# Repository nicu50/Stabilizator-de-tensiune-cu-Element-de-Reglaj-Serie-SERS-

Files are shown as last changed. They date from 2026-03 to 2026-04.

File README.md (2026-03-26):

# Stabilizator de tensiune cu Element de Reglaj Serie (SERS)

## Descriere
Acest proiect prezintă proiectarea, simularea și analiza unui stabilizator liniar cu element de reglaj serie.  
Proiectul a fost realizat în cadrul **Universitatea Politehnica din București, Facultatea de Electronică, Telecomunicații și Tehnologia Informației**.

## Principiu de funcționare
Stabilizatorul menține constantă tensiunea pe sarcină printr-un proces de reglare automată:
- O fracțiune din tensiunea de ieșire este comparată cu o tensiune de referință stabilă (diodă Zener + sursă de curent constant).
- Semnalul de eroare este amplificat și comandă elementul regulator serie (tranzistoare în conexiune Darlington).
- Include protecție la supracurent pentru a limita curentul maxim la 0,4 A.

## Cerințe de proiectare 
Să se proiecteze si realizeze un stabilizator de tensiune cu ERS având următoarele caracteristici: 
- Tensiunea de ieșire reglabilă în intervalul: N/3 – N/2 = 3.66 – 5.5[V];
- Element de reglaj serie;
- Sarcina la ieșire 50N = 550 [ohm];
- Deriva termică < 2 mV/C;
- Protecție la suprasarcină prin limitarea curentului tranzistorului element de reglaj serie la maxim 0,4 A;
- Tensiune de intrare în intervalul 2/3N - 3/4N = 7.33 – 8.25[V];
- Domeniul temperaturilor de funcționare: 0-70 C (verificabil prin testare în temperatură);
- Amplificarea în tensiune minimă (în buclă deschisă) a amplificatorului de eroare: 200; 

## Schema bloc
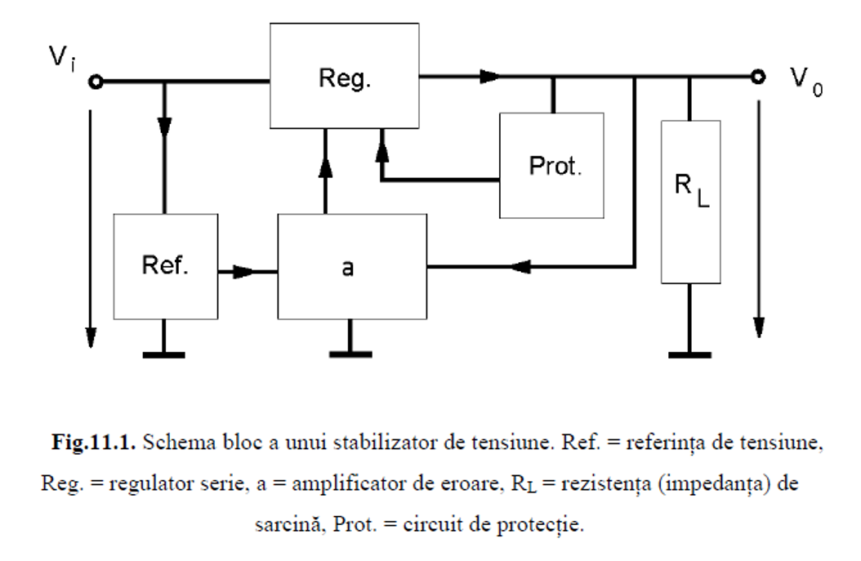
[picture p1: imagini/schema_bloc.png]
Schema bloc


## Schema electrică 
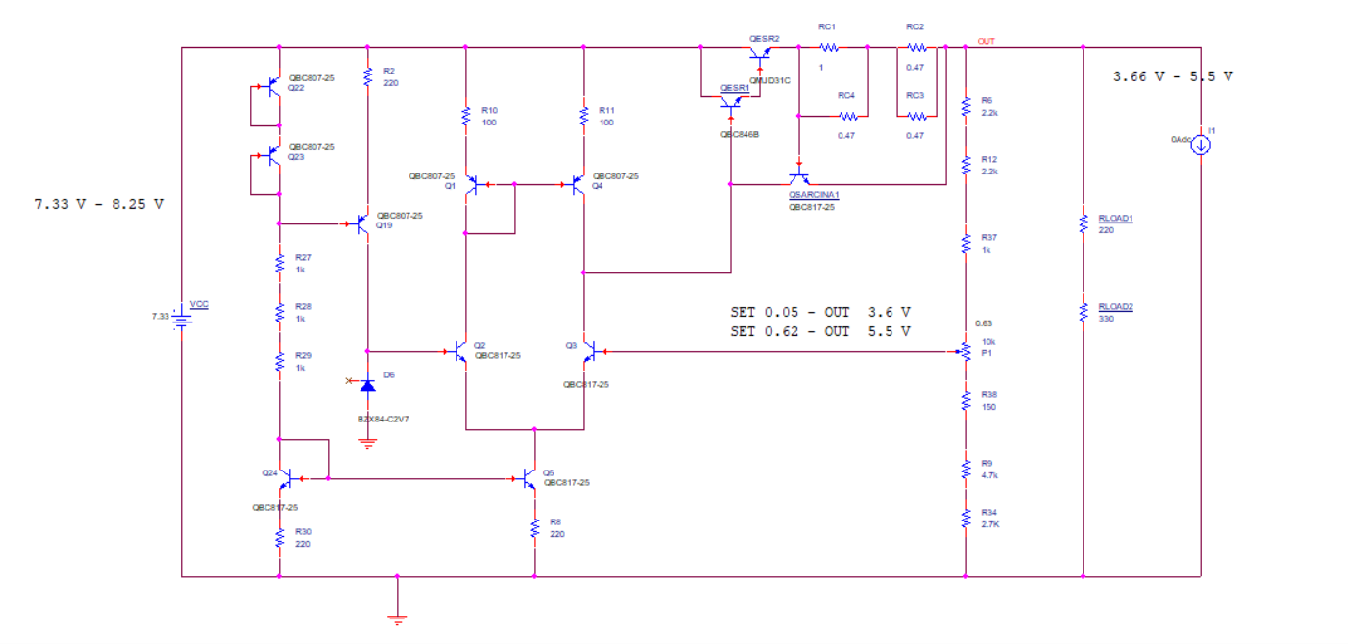
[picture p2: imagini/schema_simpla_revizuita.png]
Schema electrica


## Punctul static de funcționare
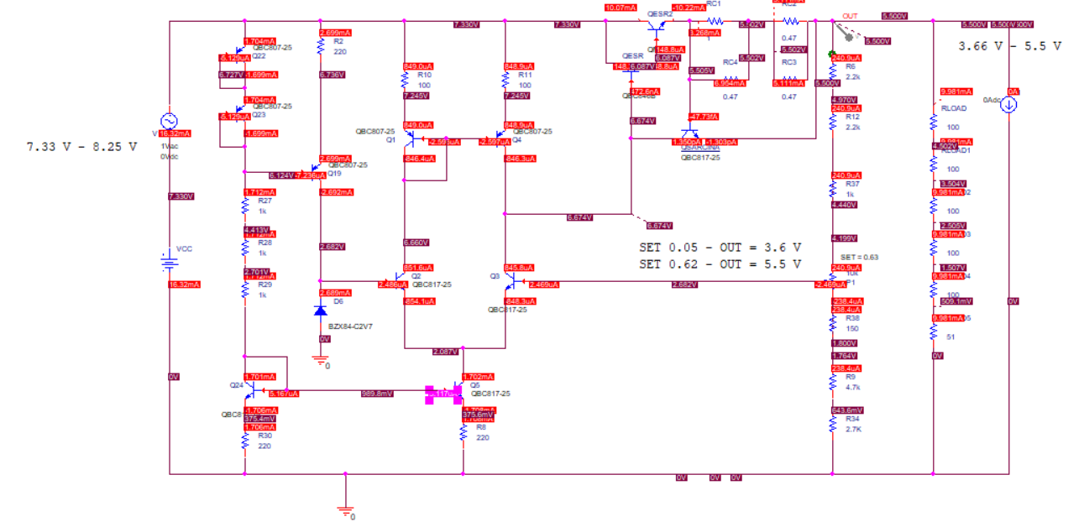
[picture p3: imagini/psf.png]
Simulare


---

## Proiectare Hardware (PCB)

Proiectul a fost realizat în tehnologie **SMT (Surface Mount Technology)** pe un cablaj dublu strat, respectând constrângerile de spațiu și specificațiile din tema de proiectare.

### Caracteristici Tehnice Cablaj:
* **Dimensiuni placă:** 40mm x 40mm
* **Material:** FR4 (dublu strat)
* **Grosime placă:** 1.5 mm
* **Grosime folie cupru:** 18 $\mu m$

### Layout PCB (Previzualizare)
Mai jos este prezentată captura de ecran cu layout-ul PCB-ului realizat în **OrCAD Allegro PCB Editor**.

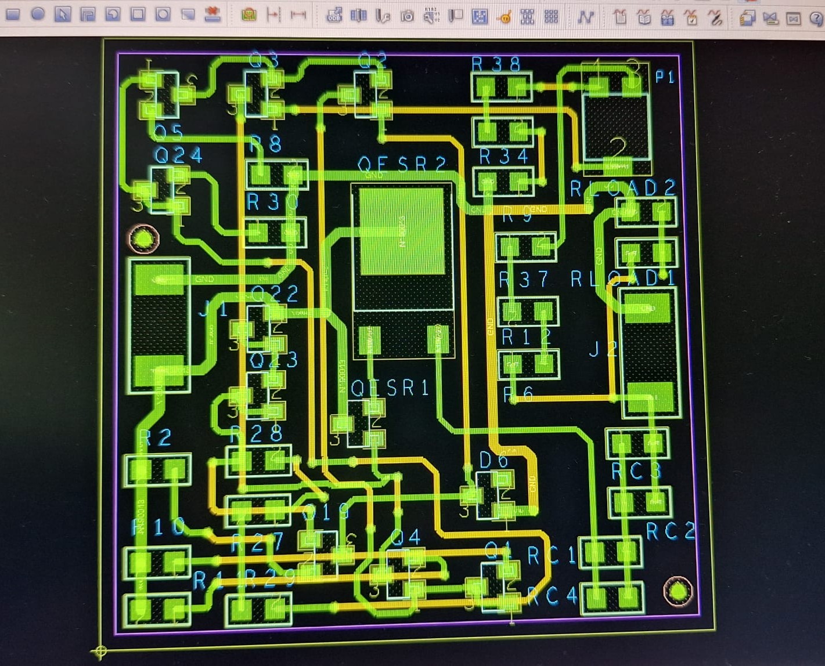
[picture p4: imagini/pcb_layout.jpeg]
Layout PCB


> **Notă:** Traseele de pe stratul TOP sunt evidențiate cu verde, iar cele de pe stratul BOTTOM cu galben.

---

## Autor
Tănăselea Neculai

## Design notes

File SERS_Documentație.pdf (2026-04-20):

## UNIVERSITATEA POLITEHNICA dinBUCUREȘTI

## Facultatea de Electronică, Telecomunicaţii şi Tehnologia Informaţiei Departamentul de Dispozitive, Circuite și Arhitecturi Electronice

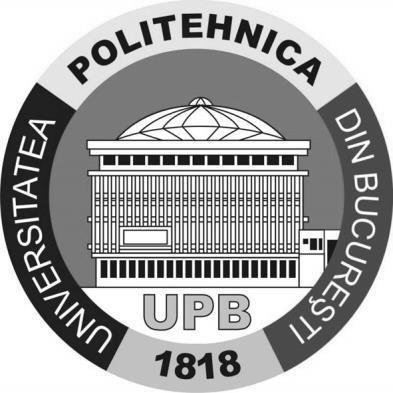
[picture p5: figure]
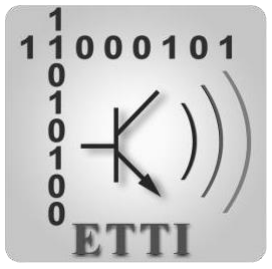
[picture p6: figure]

# PROIECT 1 Stabilizator de tensiune

## Profesori coordonatrori: Ş.l.Dr.Ing. Cristea Miron Dr.Ing. Drăghici Niculina

## Student: Tănăselea Neculai Grupa 433C Anul III

## Anul universitar 2025-2026

## CUPRINS

1. Date inițiale de proiectare | 3
1.1 Enunțul temei de proiectare | 3
1.2 Schema bloc a montajului electric | 3
1.3 Schema electrică a montajului electric | 4
2. Conținut tehnic/științific al proiectului | 5
2.1 Descrierea funcționării schemei de proiectare | 5
2.2 Proiectarea schemei electrice în ORCAD | 7
2.3 BOM | 7
2.4 Punctulstatic de funcționare (curent, tensiune, putere) | 8
3. Simularea montajului electric | 10
4. Bibliografie și webografie | 13

## 1. Date inițiale de proiectare

### 1.1 Enunțul temei de proiectare ( N=11 )

Să se proiecteze sirealizeze un stabilizator de tensiune cu ERS având următoarele caracteristici:
- Tensiunea de ieșire reglabilă în intervalul: N/3 – N/2 = 3.66 – 5.5[V];
- Element de reglajserie;
- Sarcina la ieșire 50N = 550 [ohm];
- Deriva termică < 2 mV/C;
- Protecție la suprasarcină prin limitarea curentului tranzistorului element de reglaj serie la maxim 0,4 A;
- Tensiune de intrare în intervalul 2/3N - 3/4N = 7.33 – 8.25[V];
- Domeniul temperaturilor de funcționare: 0-70 C (verificabil prin testare în temperatură);
- Amplificarea în tensiune minimă (în buclă deschisă) a amplificatorului de eroare: 200;

### 1.2 Schema bloc a montajului electric

În schemă se observă următoarele componente:
- Ref – Referința de tensiune;
- a - Amplificator de eroare;
- Reg - Regulator serie;
- RL – Rezistenta de sarcină;
- Prot. - Circuit de
protectie;
La intrarea neinversoare a Amplificatorului de eroare se aplică
Referința de tensiune, oferită de blocul
Ref.

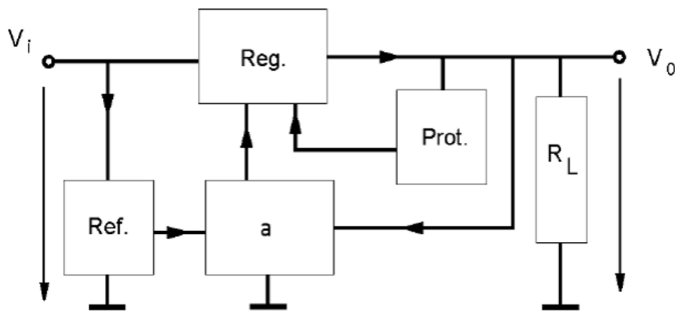
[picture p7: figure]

La intrarea inversoare a Amplificatorului de eroare se aplică, prin intermediul reacției negative, prin blocul RR, o fracțiune din tensiunea de ieșire. Regulatorul serie este comandat de Amplificatorul de eroare, care compară tensiunea dată de Referința de tensiune cu tensiunea preluată de la ieșire prin rețeaua de reacție RR. La acesta se adaugă un Circuit de protecție la suprasarcină.

### 1.3 Schema electrică a montajului electric

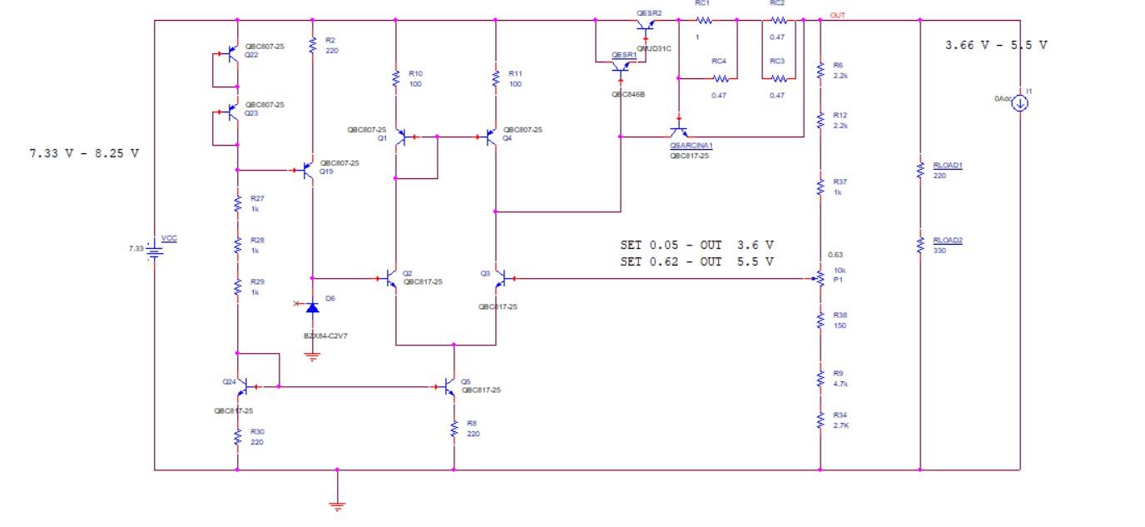
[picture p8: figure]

Circuitul este compus din următoarele blocuri:
- Q23,Q22,R27,R28,R29,Q30 genereaza curent
- Rețea reacție negativă R6, R12, R37, P1, R38, R9, R34
- Element reglaj serie: QESR1 si QESR2
- Protecția la suprasarcină: QSARCINA 1,RC1, RC2, RC3, RC4
- Q5 polarizeaza etajul diferential
- Q3 Q2 etaj diferential de tip NPN amplifica in curent si tensiune
- Q1 Q4 sarcina activa a etajului diferential egaleaza curentii pe cele doua ramuri

## 2. Conținut tehnic/științific al proiectului

### 2.1 Descrierea funcționării schemei de proiectare

Stabilizatoarele de tensiune sunt circuite electronice care mențin constantă tensiunea pe rezistența de sarcină (tensiunea stabilizată), în condițiile variației tensiunii de intrare (tensiunea nestabilizată), a curentului de sarcină și a temperaturii.
Schema prezentată este un stabilizator liniar serie cu reacție. Tensiunea de ieșire se menține constantă printr-un proces de reglare automată: o fracțiune din tensiunea de ieșire este comparată cu o tensiune de referință fixă. Semnalul de eroare rezultat este amplificat și comandă elementul regulator serie pentru a restabili valoarea prescrisă.
Stabilizatorul include protecție la supracurent, care limitează intensitatea curentului prin sarcină la o valoare presetată pentru a proteja tranzistorul regulator.

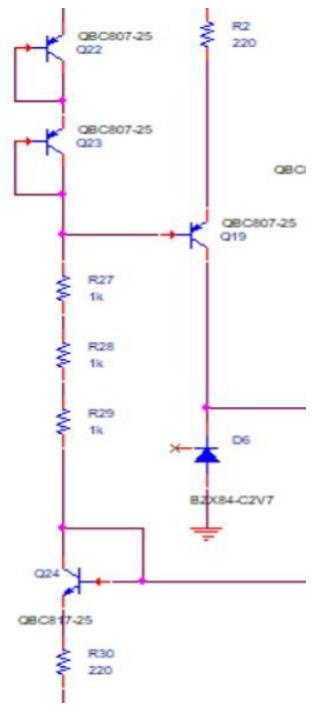
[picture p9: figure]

### 1. Referinta de tensiune

Referința de tensiune este asigurată de dioda Zener D6 (model BZX84-C2V7). Aceasta furnizează o tensiune stabilă de aproximativ 2.7 V la catodul său, care servește drept punct de comparație pentru amplificatorul de eroare.Pentru o stabilitate superioară, dioda Zener nu este alimentată printr-o simplă rezistență, ci printr-un generator de curent constant complex, format din tranzistoarele Q19, Q22, Q23, Q24 și rezistențele aferente.
Acest circuit asigură un curent constant prin dioda Zener (indiferent de fluctuațiile tensiunii de intrare VCC, garantând o tensiune de referință precisă ("zgomot" redus și impedanță dinamică mică).Componente cheie: D6 (Zener 2.7V), Q19, Q22, Q23, Q24 (Sursă de curent).

### 2. Amplificator de eroare

Amplificatorul de eroare este realizat sub forma unui amplificator diferențial cu tranzistoare bipolare. Etajul de intrare este format din perechea diferențială de tranzistoare PNP Q2 și Q3 (tip BC807-25). Baza lui Q2 primește tensiunea de referință (2.7V) de la dioda D6. Baza lui Q3 primește tensiunea de reacție (eșantionul din tensiunea de ieșire) de la potențiometrul P1.

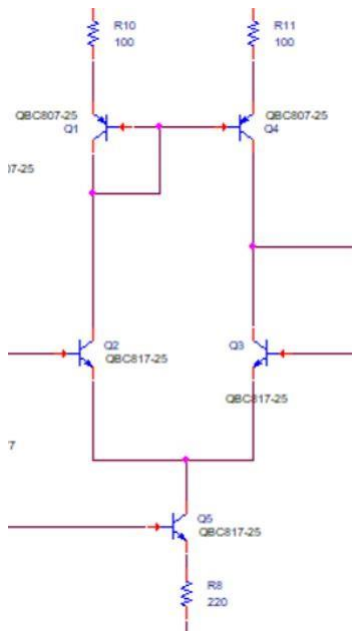
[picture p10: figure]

Sarcina acestui etaj diferențial este o oglindă de curent activă formată din tranzistoarele NPN Q2 și Q3 (tip BC817-25), care asigură o conversie eficientă a semnalului diferențial într-un semnal de comandă asimetric (single-ended) pentru etajul următor. Curentul de coadă al amplificatorului diferențial (tail current) este stabilit de tranzistorul Q5, care face parte din rețeaua de polarizare de la intrare

### 3. Element de reglaj serie

Elementulregulator serie este configurat ca o pereche Darlington, formată din tranzistorul pre-final QESR1 (BC846B) și tranzistorul de putere QESR2 (MJD31C).

În cel mai defavorabil caz (tensiune intrare maximă 8.25V și ieșire minimă 3.66V), căderea de tensiune pe tranzistor este de aproximativ 4.6V. La un curent de sarcină semnificativ, puterea disipată trebuie gestionată termic. Configurația Darlington asigură un factor de amplificare în curent (beta) foarte mare, permițând amplificatorului de eroare să comande sarcini mari cu un curent de bază foarte mic.

### 4. Rețeaua de reacție negativă

Aceasta este un divizor de tensiune rezistiv conectat la ieșirea stabilizatorului, care "citește" valoarea tensiunii de ieșire. Divizorul este compus din R37, Potențiometrul P1, R38, R9 și R34.
Tensiunea culeasă de pe cursorul potențiometrului P1 este aplicată bazei tranzistorului Q3 (intrarea inversoare a amplificatorului de eroare). Sistemul va ajusta ieșirea astfel încât tensiunea pe cursorul lui P1 să fie egală cu tensiunea de referință (2.7V).
Reglaj: Prin variația lui P1 (10k), se modifică raportul de divizare, permițând reglarea tensiunii de ieșire (OUT) în intervalul proiectat de aproximativ 3.6V – 5.5V.

### 5. Circuit de protecție

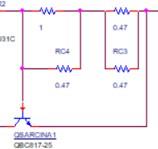
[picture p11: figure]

Schema este prevăzută cu un circuit de protecție la supracurent (limitare de curent), esențial pentru protejarea tranzistorului de putere QESR2 în cazul unui scurtcircuit sau al unei sarcini excesive.
Protecția este realizată cu tranzistorul QSARCINA1 (BC817-25) și grupul de rezistențe de sesizare a curentului conectate în serie cu ieșirea: RC1, RC4, RC3, RC2. Aceste rezistențe sunt conectate în paralel pentru a obține o valoare ohmică foarte mică și o capacitate de putere mai mare.

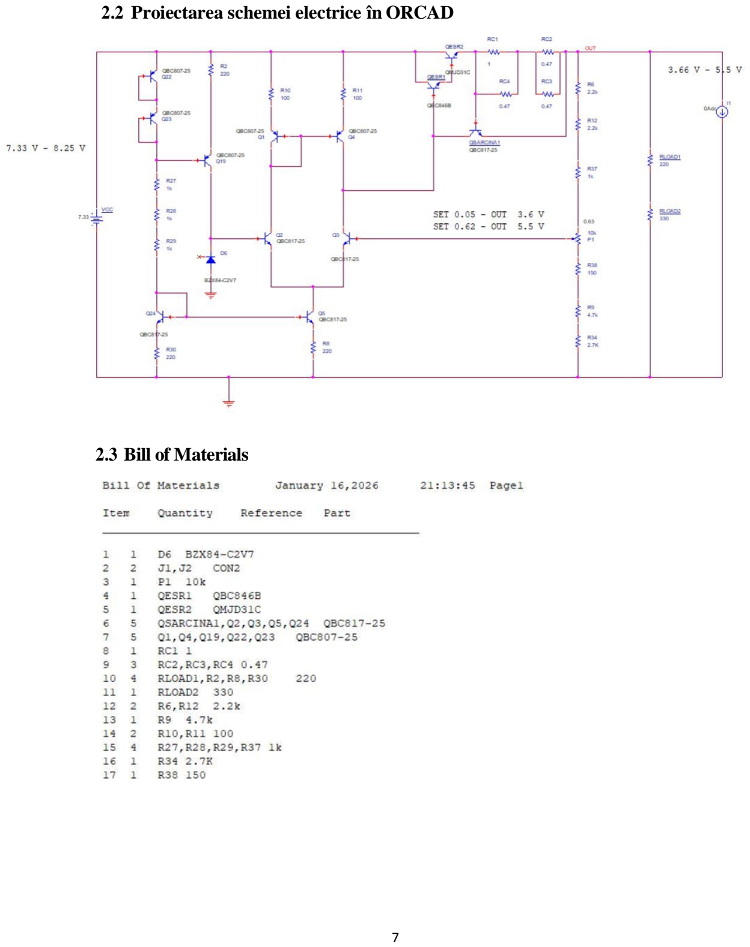
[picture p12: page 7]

### 2.2 Proiectarea schemei electrice în ORCAD

### 2.3 Bill of Materials

### 2.4 Punctulstatic de funcționare

1) CURENTI

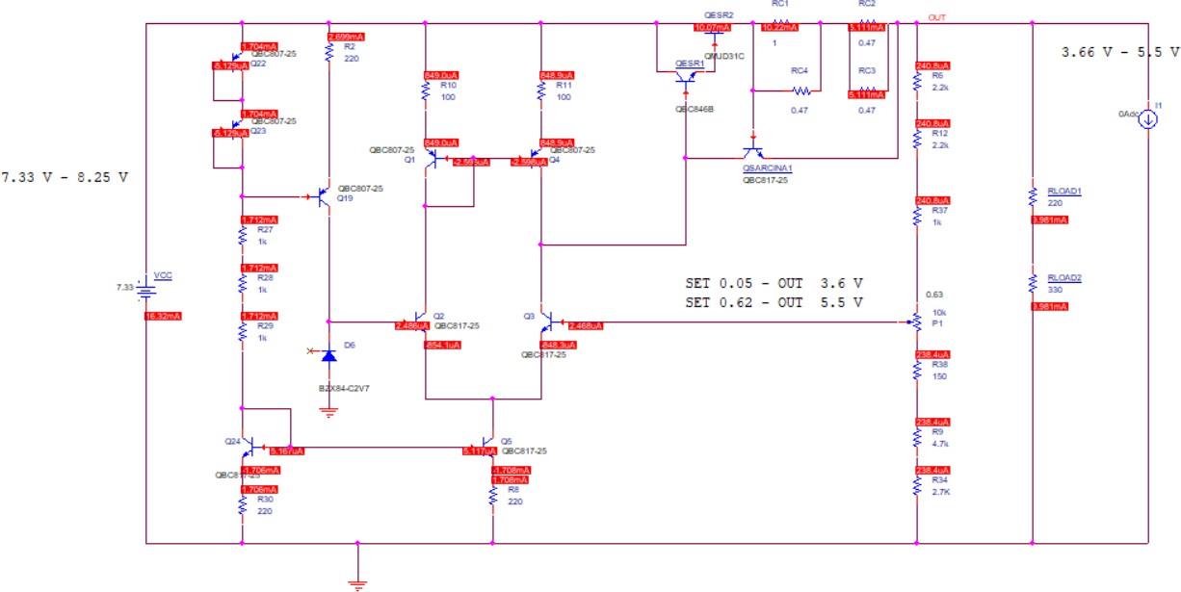
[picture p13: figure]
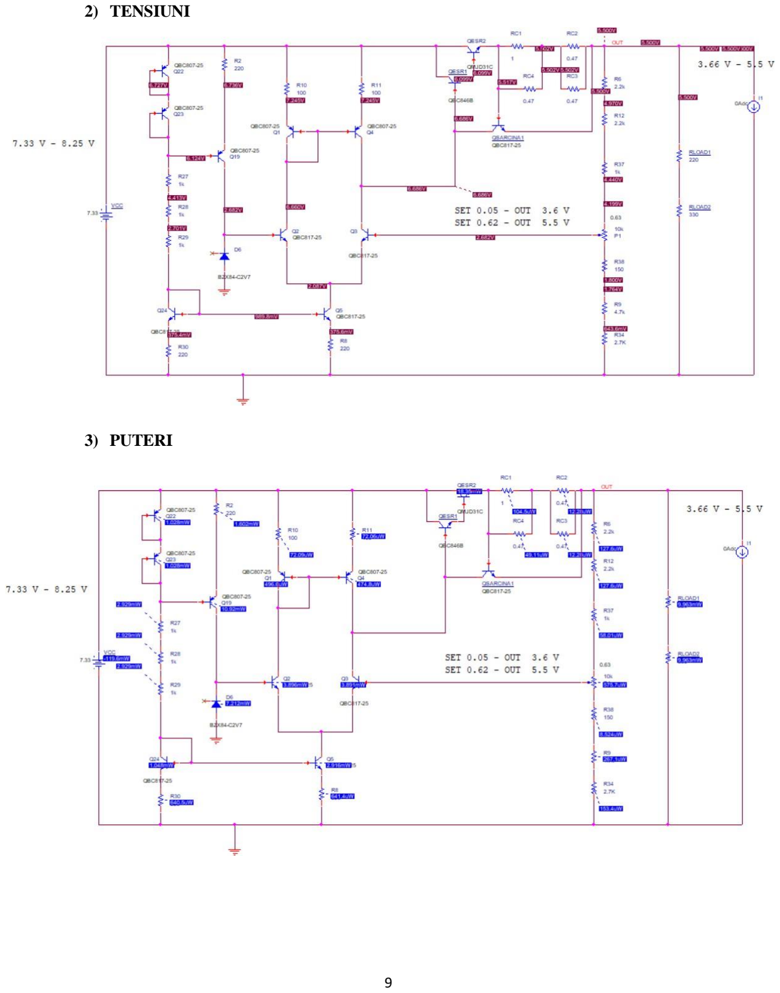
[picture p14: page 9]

2) TENSIUNI
3) PUTERI

## 3 Simularea montajului electric

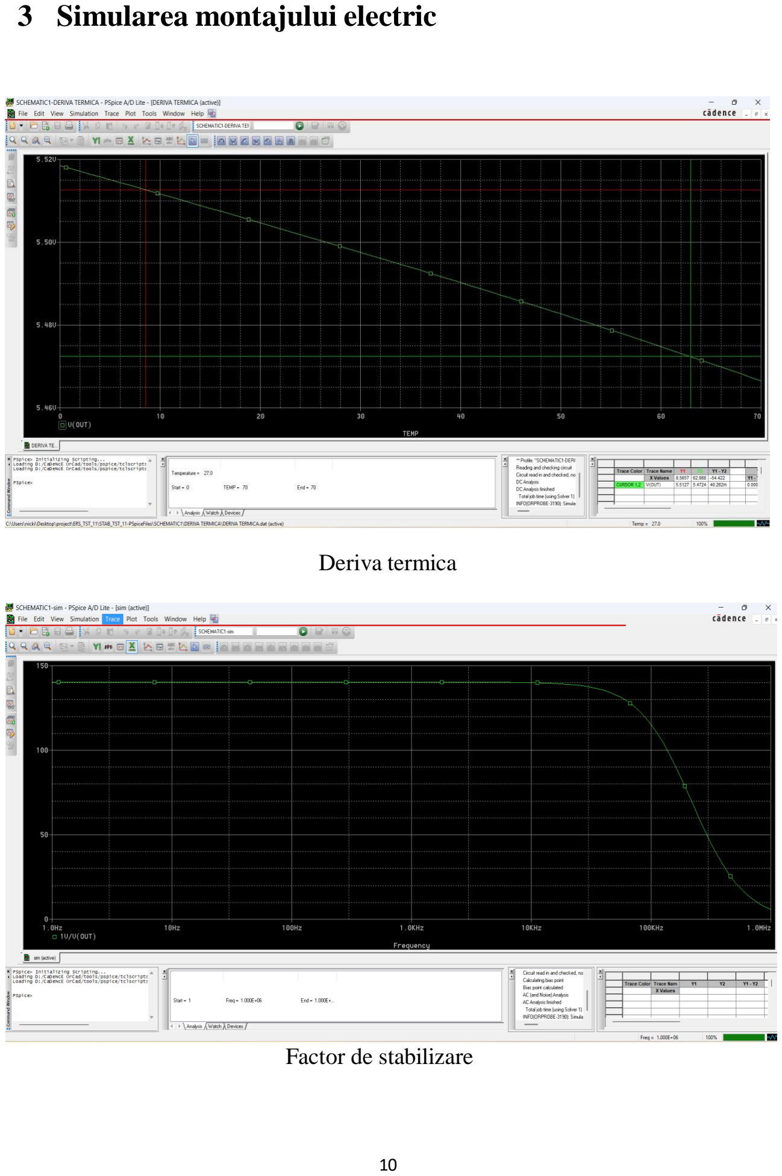
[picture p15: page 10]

Deriva termica

Factor de stabilizare

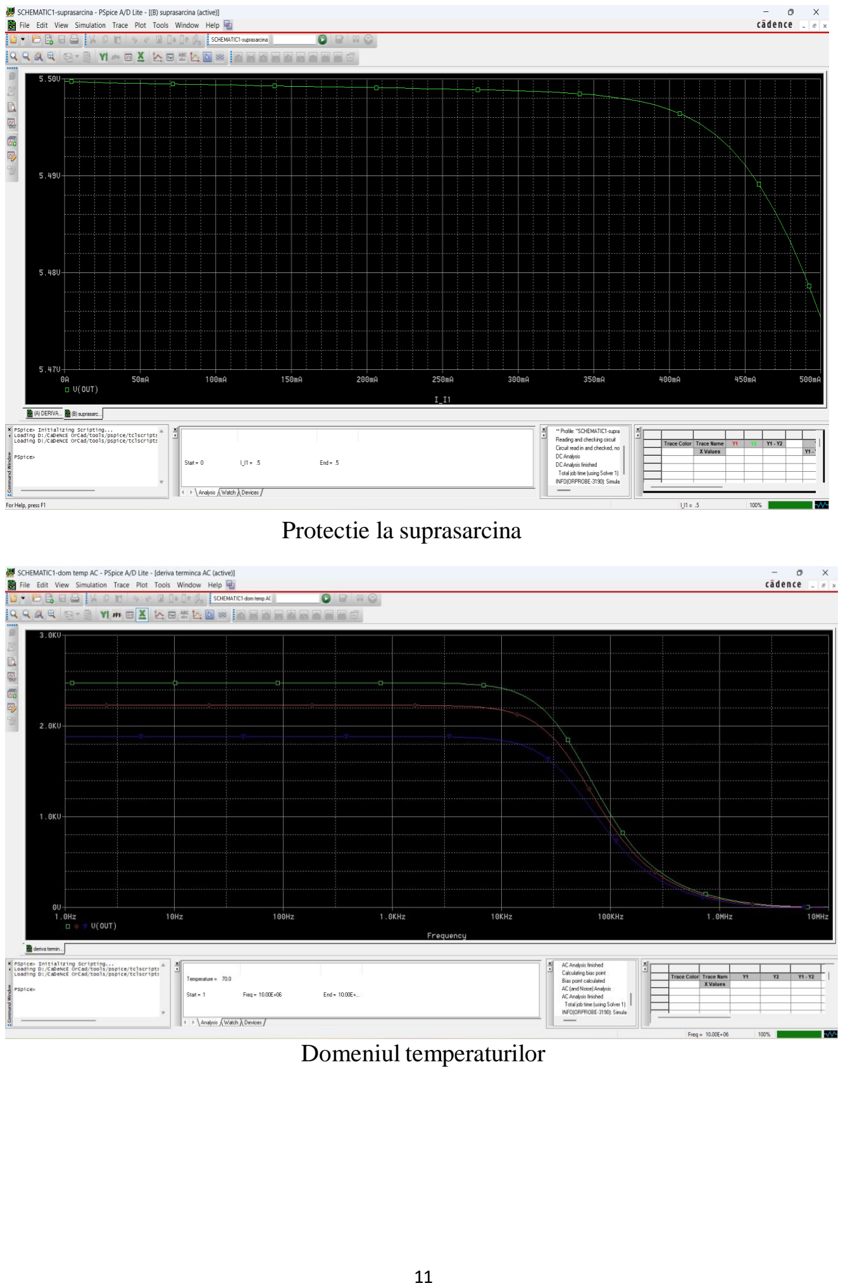
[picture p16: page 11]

Protectie la suprasarcina

Domeniul temperaturilor

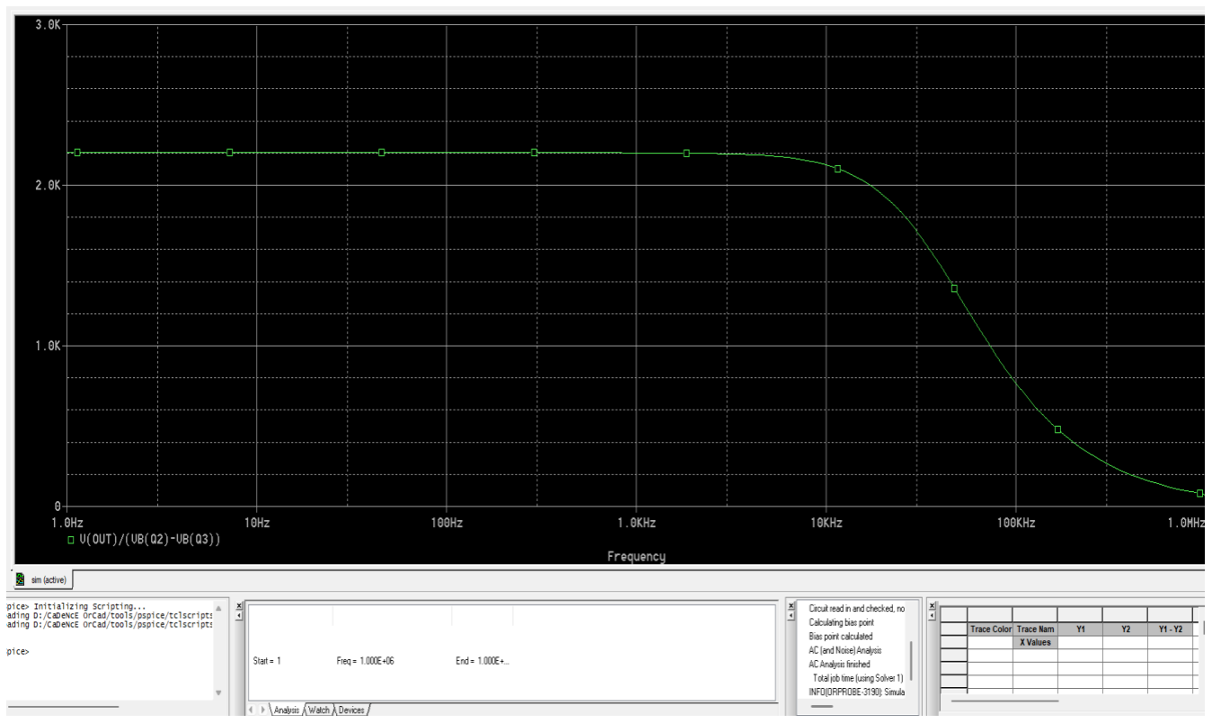
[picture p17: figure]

Amplificare bucla deschisa

## 4 Bibliografie și webografie

- BREZEANU GH., DRĂGHICI F., DILIMOȚ GH., MITU F., Circuite electronice fundamentale, București, Editura ROSETTI EDUCATIONAL, 2009
- CODREANU N., PANTAZICĂ M., IONESCU C., MARCU A., Tehnici CAD de realizarea modulelor electronice, București, Editura CAVALLIOTI, 2017
- DASCĂLU D., RUSU A., PROFIRESCU M., COSTEA I., Dispozitive și circuite electronice, București, Ed. DIDACTICĂ ȘI PEDAGOGICĂ, 1983;
- https://resources.orcad.com
